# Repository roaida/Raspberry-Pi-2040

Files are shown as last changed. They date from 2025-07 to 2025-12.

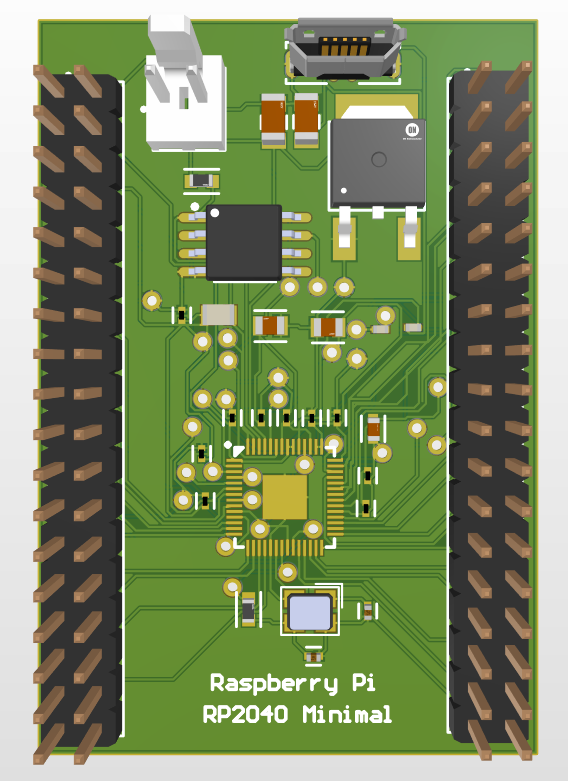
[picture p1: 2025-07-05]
IMG/Screenshot 2025-07-05 210902.png

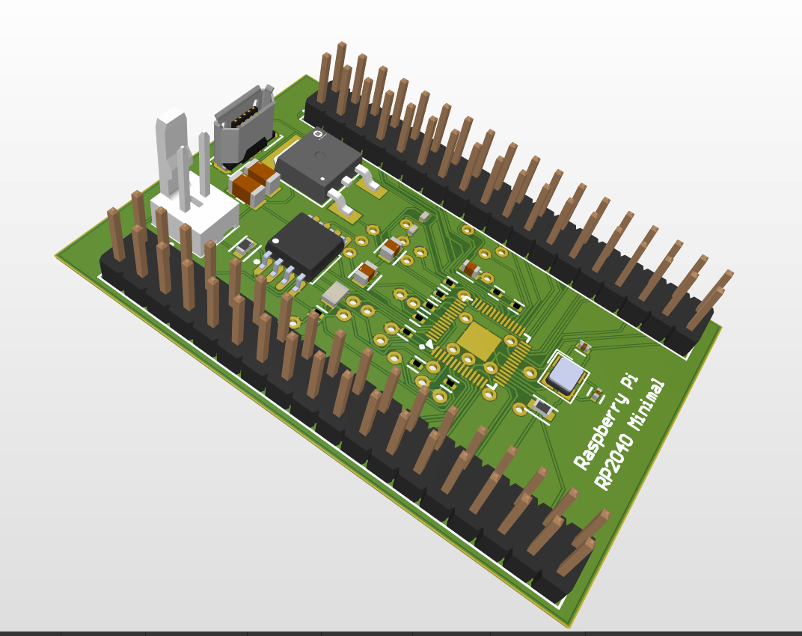
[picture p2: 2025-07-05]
IMG/Screenshot 2025-07-05 210955.png

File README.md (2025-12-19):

# 🔌Raspberry Pi RP2040 Minimal Board (Sponsored by PCBWay)

A compact, minimal circuit design for the Raspberry Pi RP2040 microcontroller. This board includes essential components for booting, programming via USB, and running custom embedded applications.
---

## 📦 Features
- ✅ RP2040 Dual-core ARM Cortex-M0+ MCU (QFN-56)
- 💾 16MB QSPI Flash (W25Q128JVSIQ)
- 🔋 3.3V LDO Regulator (NCP1117)
- 🔌 USB interface for power and programming
- ⏱️ 12 MHz Crystal Oscillator
- 🎚️ Exposed GPIO headers for external interfacing
- 🧰 BOOTSEL and RESET jumper logic
- 🧪 SWD interface for debugging (optional)
---

## 🧠 Working Mechanism

### 1. **Power Supply**
- USB 5V (VBUS) enters via micro USB (J1).
- The **NCP1117** regulator converts 5V → 3.3V.
- 3.3V powers the **RP2040**, **flash**, and **I/O**.

### 2. **Clock Generation**
- A 12 MHz crystal oscillator (U1) provides the reference clock.
- RP2040 uses this to generate internal system clocks via PLL.

### 3. **Boot Process**
- RP2040 checks `QSPI_SS` (Pin 56) during reset:
  - **HIGH** → Boot from QSPI Flash (U4)
  - **LOW** → Enter BOOTSEL (USB Mass Storage Mode)
- Code is read directly from flash using **QSPI** interface.

### 4. **Firmware Upload**
- Short the **USB_BOOT jumper (P3)** and toggle the **RUN pin** to enter BOOTSEL mode.
- Upload `.UF2` firmware file directly via USB.

### 5. **Program Execution**
- Once booted, the MCU runs user code:
  - Controls GPIO
  - Reads ADC (GPIO26–29)
  - Communicates via USB, UART, I2C, SPI, etc.

### 6. **Debugging (Optional)**
- **SWD/SWCLK** pins exposed for JTAG/SWD debugging tools.
---

## 🧩 Key Components

| Ref | Component | Description |
|-----|---|---|
| U3  | RP2040 | Main microcontroller |
| U4  | W25Q128JV | 16MB QSPI Flash |
| U2  | NCP1117 | 3.3V LDO Regulator |
| U1  | ABM8-272-T3 | 12 MHz Crystal Oscillator |
| J1  | USB | Power & USB communication |
| R2, R3 | 27Ω | USB D+ / D− termination |
| Cx  | Capacitors | Power filtering & stability |
| P1, P2 | Headers | GPIO & ADC access |
| P3  | Jumper | USB_BOOT selector |

---

## 🗺️ Schematic & PCB
- ✅ Included in `/hardware/PI.SchDoc` and `/hardware/PI.PcbDoc`
- Designed using **Altium Designer**
- Compact layout optimized for signal integrity and EMI performance

---

## 🔧 How to Use
1. Connect via USB.
2. Short `USB_BOOT` jumper and toggle `RUN` to enter BOOTSEL mode.
3. Drag and drop your `.UF2` firmware file.
4. Board reboots and runs your program.
---

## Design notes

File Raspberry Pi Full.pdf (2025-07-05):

# 🧾 Functional Notes for RP2040 Minimal Board Design

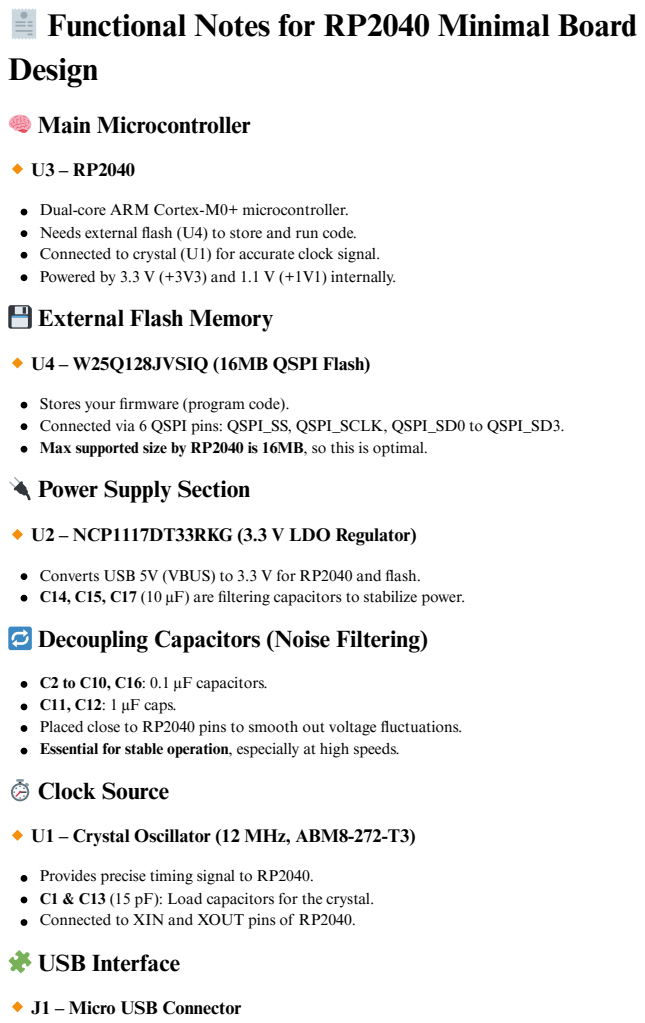
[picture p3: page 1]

Dual-core ARM Cortex-M0+ microcontroller.
Needs external flash (U4) to store and run code.
Connected to crystal (U1) for accurate clock signal.
Powered by 3.3 V (+3V3) and 1.1 V (+1V1) internally.
💾 External Flash Memory

Stores your firmware (program code).
Connected via 6 QSPI pins: QSPI_SS, QSPI_SCLK, QSPI_SD0 to QSPI_SD3.
Max supported size by RP2040 is 16MB, so this is optimal.
🔌 Power Supply Section

Converts USB 5V (VBUS) to 3.3 V for RP2040 and flash.
C14, C15, C17 (10 µF) are filtering capacitors to stabilize power.
🔁 Decoupling Capacitors (Noise Filtering)

C2 to C10, C16: 0.1 µF capacitors.
C11, C12: 1 µF caps.
Placed close to RP2040 pins to smooth out voltage fluctuations.
Essential for stable operation, especially at high speeds.
⏱️ Clock Source

Provides precise timing signal to RP2040.
C1 & C13 (15 pF): Load capacitors for the crystal.
Connected to XIN and XOUT pins of RP2040.
🧩 USB Interface

Used to provide power and data to the board.
Pins D+ and D− connected via resistors R2, R3 (27Ω) to RP2040. Connects to computer for USB communication (programming, debugging). R4 marked DNF: Optional pull-up for flash chip’s QSPI_SS.

## 🆗 BOOT Mode Circuit

🔸 R5 – 1kΩ + P3 Header (USB_BOOT)

Allows forcing RP2040 into USB BOOTSEL mode.
When P3 is shorted (jumper added) and RESET is toggled, RP2040 enters USB programming mode. Useful for uploading firmware without a programmer.

## 🔄 RUN & RESET Logic

🔸 RUN pin: Connected to a header (P2-29), allows external reset.

Pulling this pin low resets the RP2040.

## 🧪 Debug Interface (Optional)

SWD and SWCLK (P2-31, P2-33): Used for in-circuit debugging with external debugger like a J-Link.
Not required for normal use, but very useful for development.

## 🌐 General Purpose I/Os (GPIOs)

P1 & P2 headers give access to all GPIOs (GPI00 to GPI029, including analog-capable ones). Some pins (GPIO26–GPIO29) can be used as ADC (analog input).

## 📦 Other Notable Info

Label | Function
+3V3, +1V1 | Power rails (regulated and internal)
GND | Ground reference for all components
C17 | Bulk capacitor for +3V3 stability
P1, P2 | 2×36 pin headers for GPIOs
U3-57 | GND exposed pad of RP2040

## 🧩 Board Summary

This board is a minimal but complete system to run RP2040 with:

Program storage (QSPI flash),
Power regulation (LDO),
USB interface (programming/data), Reset and BOOT options,
GPIO headers for external interfacing.

# ⚙️ Working Mechanism of the RP2040 Minimal Board

## 🔋 1. Power-Up Sequence

Power is supplied via the USB connector (J1).
VBUS (5V) from USB goes into the 3.3V regulator (U2: NCP1117DT33RKG). The regulator converts 5V into +3.3V, which powers:
The RP2040 (U3)
The flash memory (U4)
All I/O devices through the +3V3 rail
Internal to RP2040, a Low Dropout Regulator (LDO) converts 3.3V to 1.1V (core voltage) via LDOOUT.

💡 Capacitors (C14, C15, C17, C2–C12) ensure the voltage remains stable and noise-free.

## ⏱️ 2. Clock Initialization

The 12 MHz crystal oscillator (U1) connected to RP2040's XIN and XOUT pins provides an accurate reference clock.
Load capacitors (C1, C13) are tuned to match the crystal's required load.
RP2040 uses this input to generate internal clock signals via its PLL (Phase-Locked Loop).

## 🧠 3. Boot Process

When RP2040 is powered or reset:

✅ a. Checks QSPI_SS Pin (Pin 56):

If QSPI_SS is HIGH, RP2040 boots from the external flash (U4).
If QSPI_SS is LOW (via jumper on P3), it enters BOOTSEL (USB Mass Storage Mode).

✅ b. Boot from Flash Memory (U4)

Flash memory stores the firmware (your program).
RP2040 reads code using the QSPI interface (6 pins: QSPI_SS, SCLK, SD0–SD3).
Executes code directly from flash (XIP = Execute in Place).

🧠 If BOOTSEL mode is entered, the board appears as a USB drive. You can drag and drop a .UF2 firmware file.

## 📲 4. USB Communication

USB D+ and D− (pins from J1) connect to RP2040 via resistors R2 and R3 (27Ω). Allows communication with a computer:
Programming via UF2 bootloader
Serial monitor output
USB device functionality (e.g., keyboard, mouse)

## 🧠 5. Program Execution

Once the code is loaded into the flash and RP2040 boots, the program runs automatically. Your program can:
Control GPIO pins
Read analog inputs (GPIO26–29)
Send/receive data via UART, I2C, SPI Use USB for HID/CDC tasks

## 🔁 6. Reset and USB_BOOT Functions

RUN pin (P2-29): When pulled LOW momentarily, resets the microcontroller. USB_BOOT jumper (P3):
Pulls QSPI_SS LOW
On next reset, forces entry into BOOTSEL mode (for firmware upload)

## 🧪 7. Debugging (Optional)

Pins SWD and SWCLK (P2-31, P2-33) allow connection to a debugger (e.g., J-Link). Useful during development for breakpoints, stepping, etc.

## 🔌 8. I/O and Expansion

P1 and P2 headers expose all RP2040 GPIOs.
Can connect sensors, buttons, LEDs, displays, etc.
Pins 26–29 can be used for analog sensors (ADC inputs).

# 🔚 Summary Flowchart:

[USB Plugged In]

↓

[5V VBUS → LDO Regulator (U2)] → [3.3V to RP2040 and Flash]

↓

[RP2040 Powers Up]

↓

[Crystal → Clock Initialized]

↓

[BOOT Check: QSPI_SS HIGH → Run Code | LOW → USB BOOT Mode]

↓

[RP2040 Reads Program from Flash via QSPI]

↓

[Program Executes → Controls GPIO, USB, ADC, etc.]

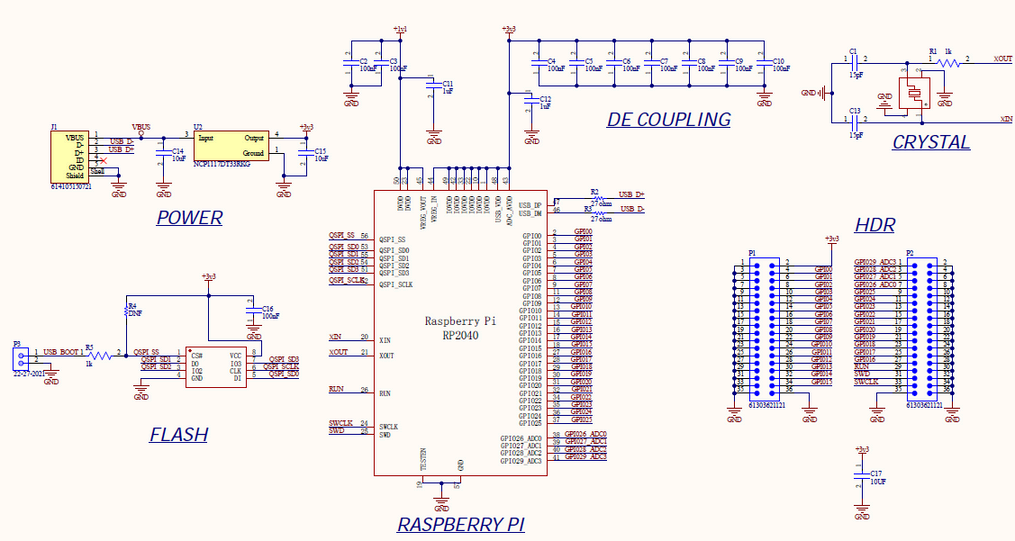
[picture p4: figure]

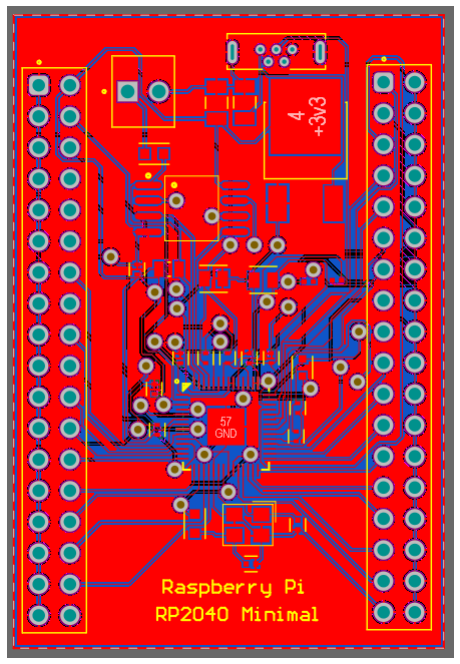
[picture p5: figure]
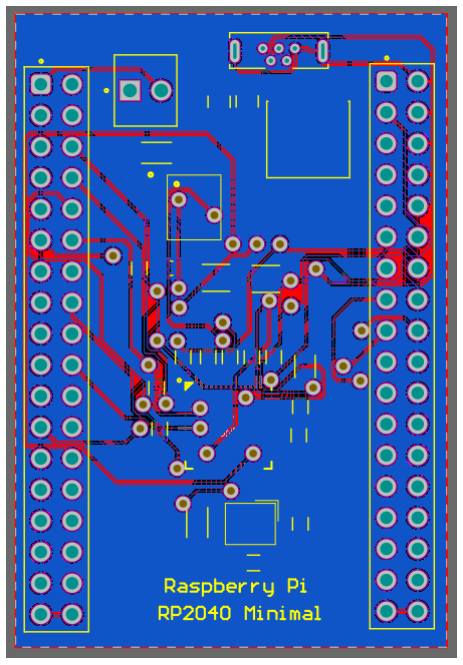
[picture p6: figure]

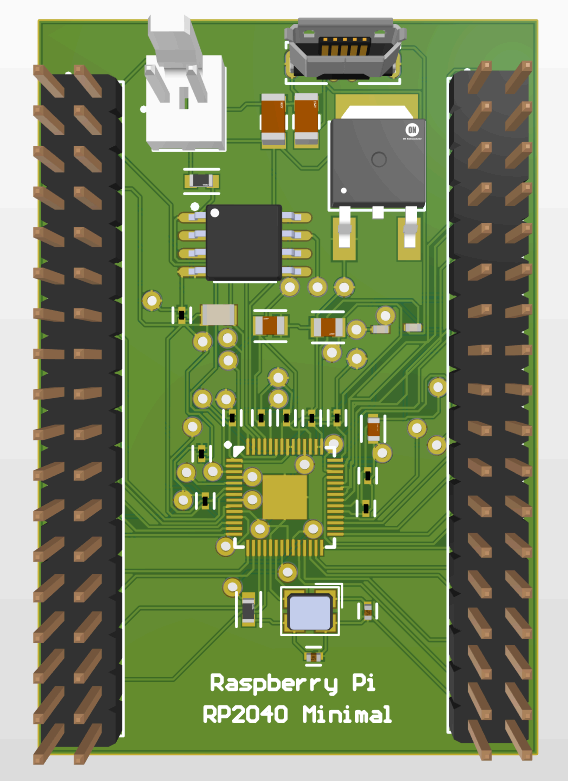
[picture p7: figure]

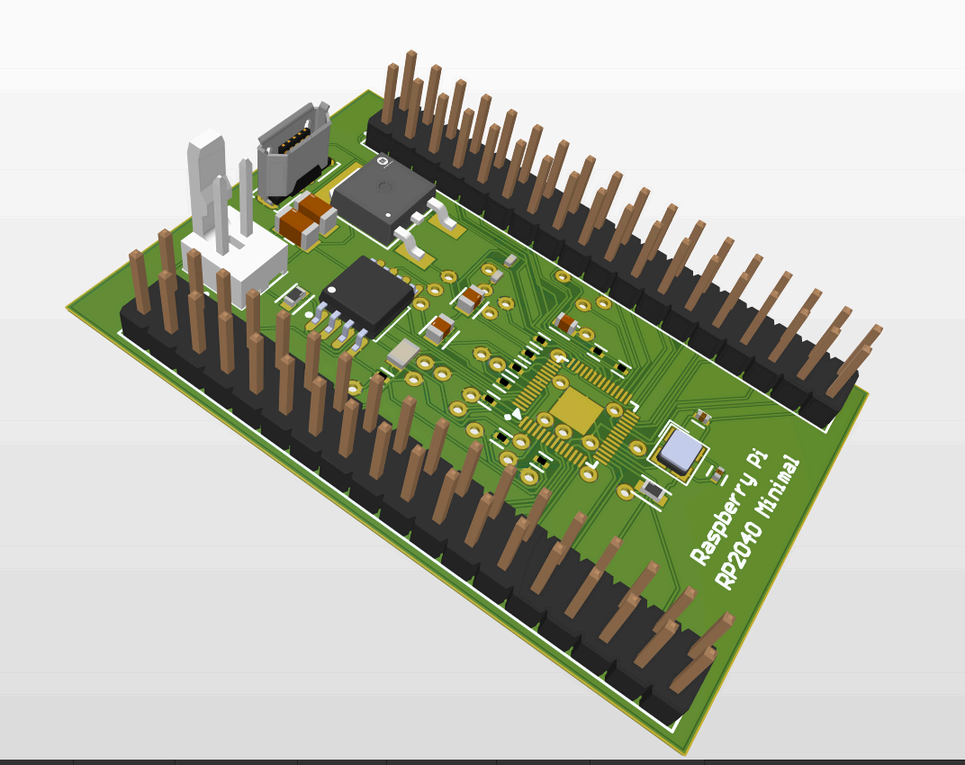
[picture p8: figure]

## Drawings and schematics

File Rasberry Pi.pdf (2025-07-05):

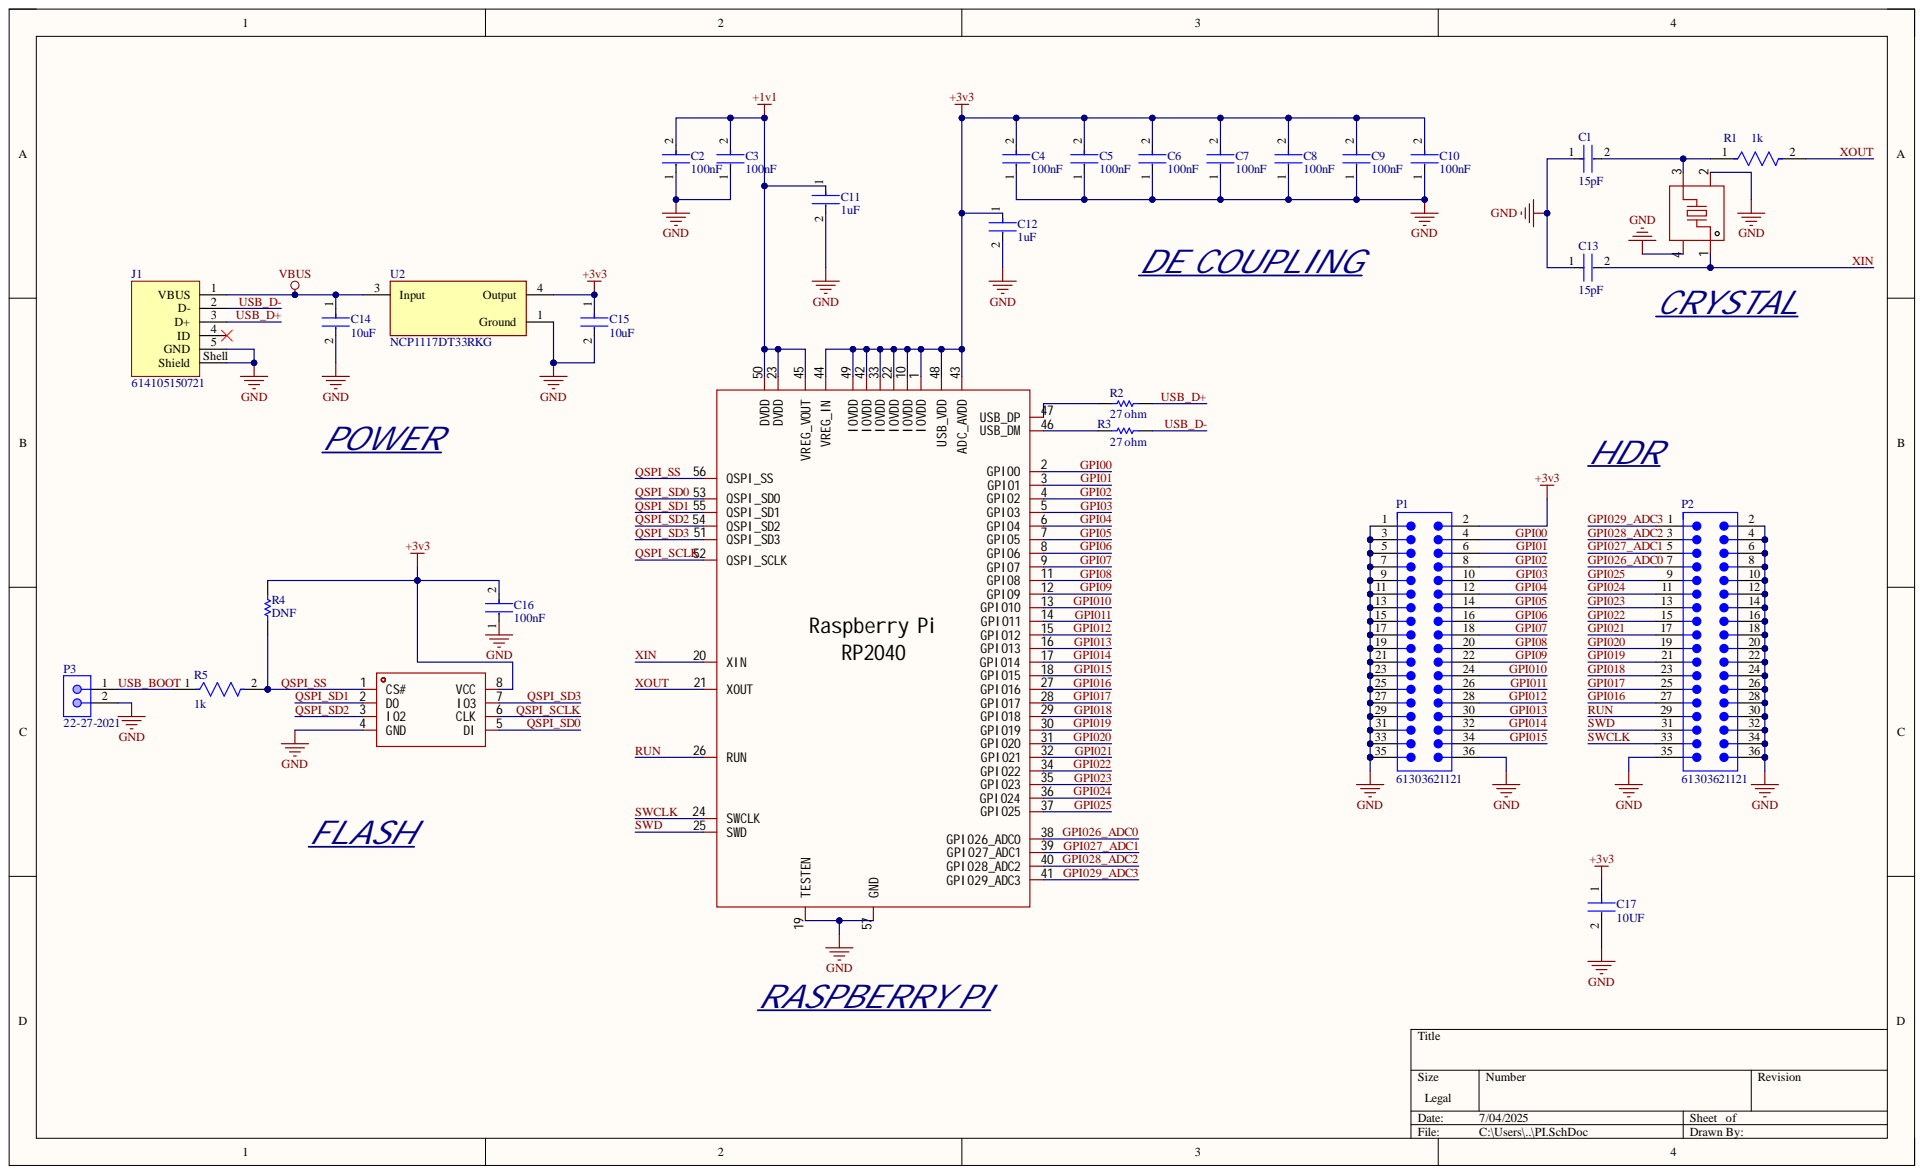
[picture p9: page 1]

Le g a l | mb e r | Re visio n

Date : 7/0 4 /2 0 2 5 | S h e et o f
File : C:\Users\. .\PI. S c hDo c | Drawn By :

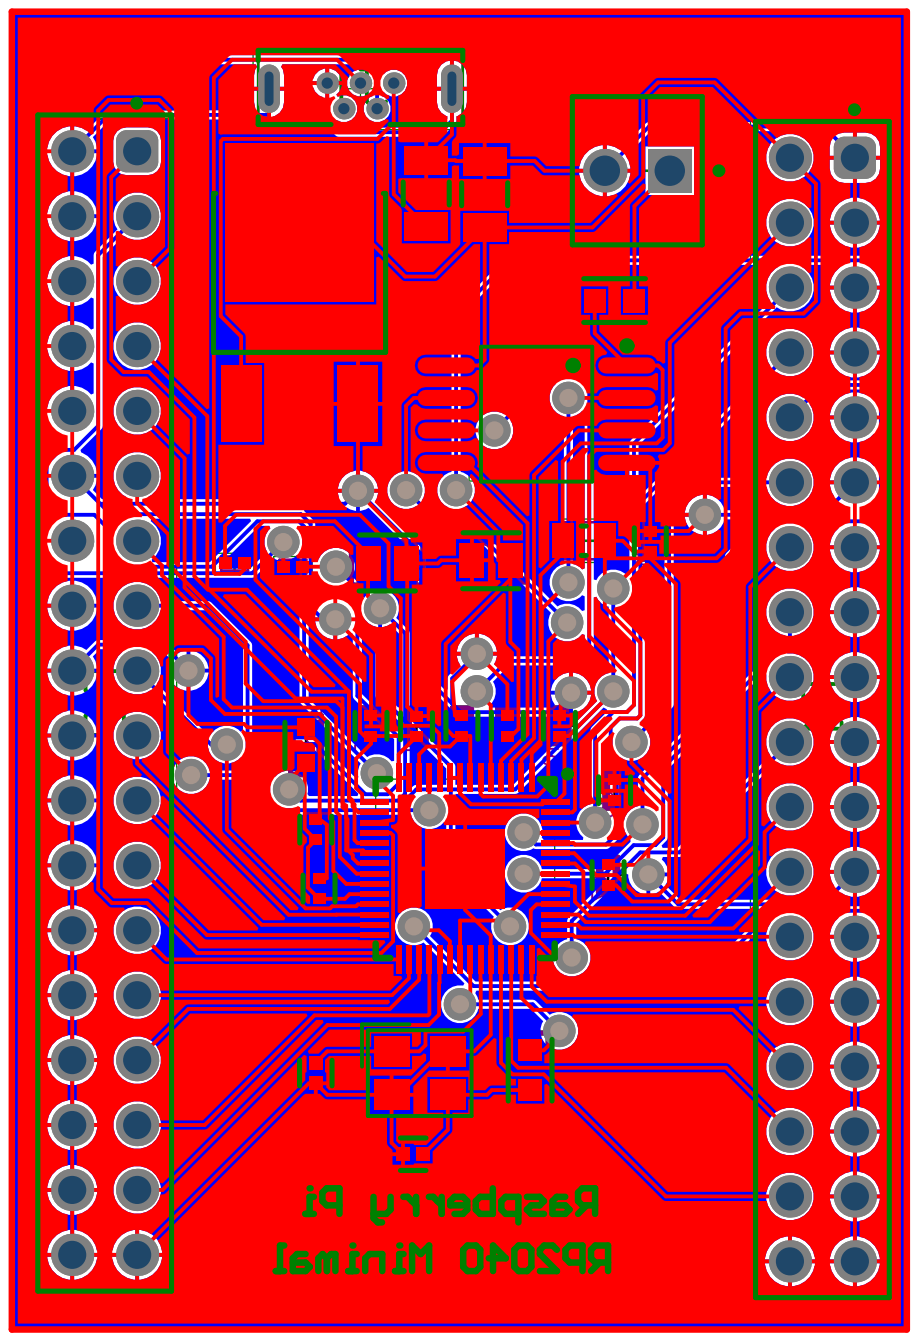
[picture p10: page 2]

Comment | Description | Designator | Footprint | LibRef | Quantity
15pF | CAPCER15PF16V5% NP00402 | C1, C13 | FP-C0402-BB-MFG | CMP-1034-00802-4 | 2
100nF | CAPCER0.1UF16V X7R0402 | C2, C3, C4, C5, C6, C7, C8, C9, C10, C16 | FP-GRM15-MFG | CMP-2100-03641-2 | 10
1uF | CAPCER1UF16VY5V 0805 | C11, C12 | FP-C0805C105Z4VACTU-MFG | CMP-2007-03241-2 | 2
10uF | General Purpose Ceramic Capacitor, 1206, 10uF, 10%, X7R, 15%, 16V | C14, C15 | FP-1206-L_3_2_0_2-W_1_6_0-IPC_C | CMP-1661-00005-2 | 2
10UF | Multilayer Ceramic Capacitor 10uF16V X5R20%SMD0603 T/R | C17 | FP-0603-L_1_6_0_2-W_0_8_0-MFG | CMP-2000-06226-4 | 1
614105150721 | | J1 | 614105150721 | CMP-1502-03250-2 | 1
61303621121 | | P1, P2 | 61303621121 | CMP-1502-01131-3 | 2
22-27-2021 | MaleHeader, Pitch 2.54mm, 1x2 Position, Height 11.7 mm, Tail Length3.56 mm, 0to75degC, RoHS, Bulk | P3 | MOLX-22-27-2021_V | CMP-2000-05537-1 | 1
1k | RES1kΩ1.00%0.1W 0603 | R1, R5 | FP-AC0603-IPC_B | CMP-2000-04828-3 | 2
27ohm | | R2, R3 | RESC1005X40X25LL05 T10 | CMP-2002-07055-1 | 2
DNF | | R4 | RESC2013X50X30LL20 T20 | CMP-2001-04896-1 | 1
ABM8-272-T3 | | U1 | CRYSTAL-SMD_4P-L3.2-W2.5-BL | ABM8-272-T3_C20625731 | 1
NCP1117DT33RKG | ICREGLINEAR3.3V1A DPAK-3 | U2 | FP-369C-MFG | CMP-07128-000036-1 | 1
RP2040 | | U3 | LQFN-56_L7.0-W7.0-P0.4-EP | RP2040_C2040 | 1
W25Q128JVSIQ | | U4 | SOIC-8_L5.3-W5.3-P1.27-LS8.0-BL | W25Q128JVSIQ | 1
